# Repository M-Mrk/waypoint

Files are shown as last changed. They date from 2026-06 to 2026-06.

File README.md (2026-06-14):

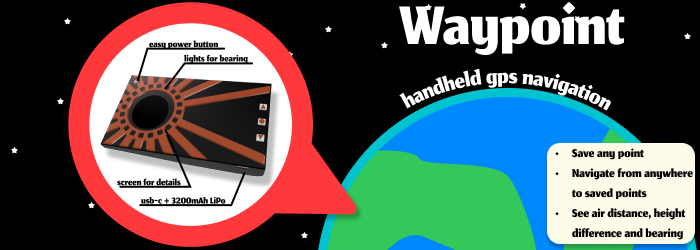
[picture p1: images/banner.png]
banner image


# Waypoint
A handheld GNSS navigation device designed to help you to get to a destination without relying on mobile reception.

Ever wanted to get somewhere from anywhere? Waypoint uses GNSS to guide you towards your destination by showing the direction, distance, and elevation difference. It does not provide turn-by-turn routes, but instead gives you all the other needed informations to navigate independently.

It is powered by a 3200mAh LiPo battery, an efficient MCU, and separated power domains to achieve long battery life.

## How to use it

1. Save your current location
2. Travel somewhere else
3. Select your saved location
4. Navigate back using the provided direction and distance information

## Why

I built Waypoint for [Fallout 2026](https://fallout.hackclub.com) because I wanted to create a project involving RF and battery management.

With this project I learned a lot about embedded Rust with the embassy framework.

## Specs
- 20 sk6812s LEDs to indicate the needed bearing
- 240x240 GC9A01 oled screen
- ATGM336H GNSS module
- Esp32-c6
- usb-c charging
- imu + magnetometer
- haptics (DRV2605L + LRE)

# Pictures
## Full assembly
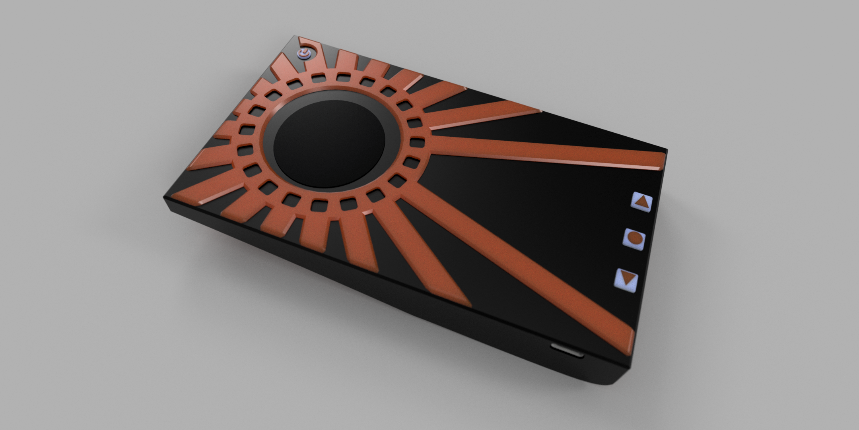
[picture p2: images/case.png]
case


## PCB
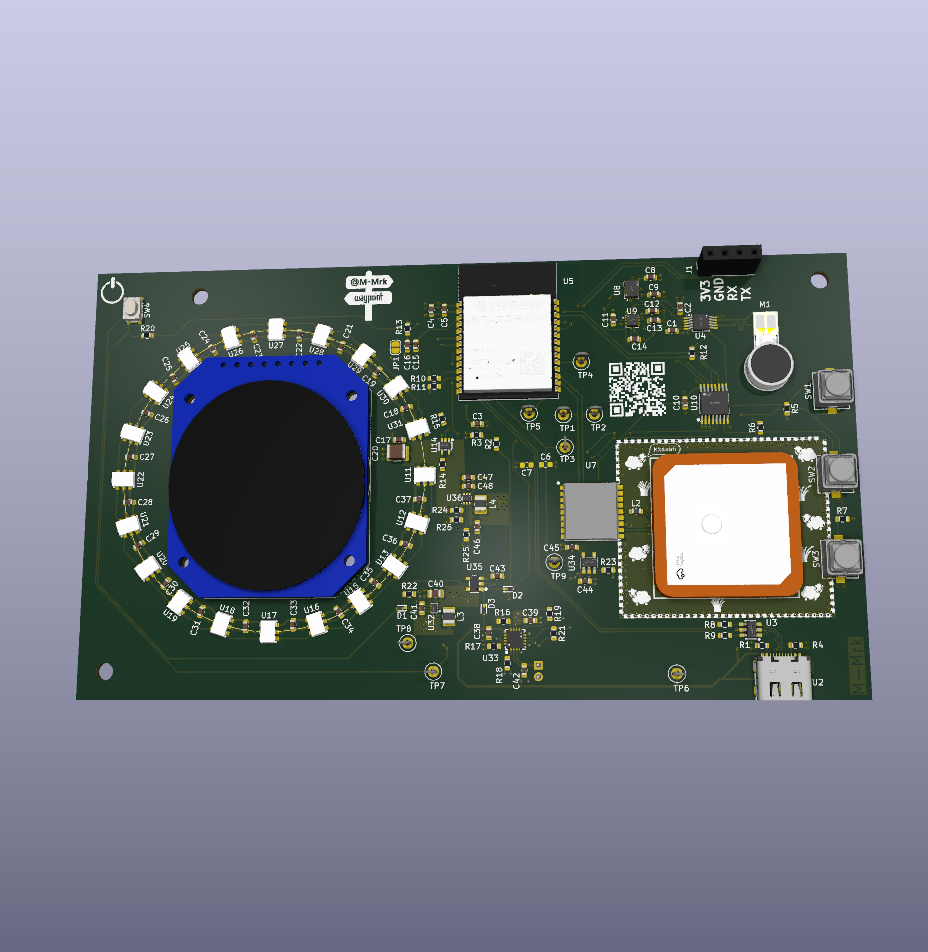
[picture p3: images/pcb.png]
pcb


## Magazine page
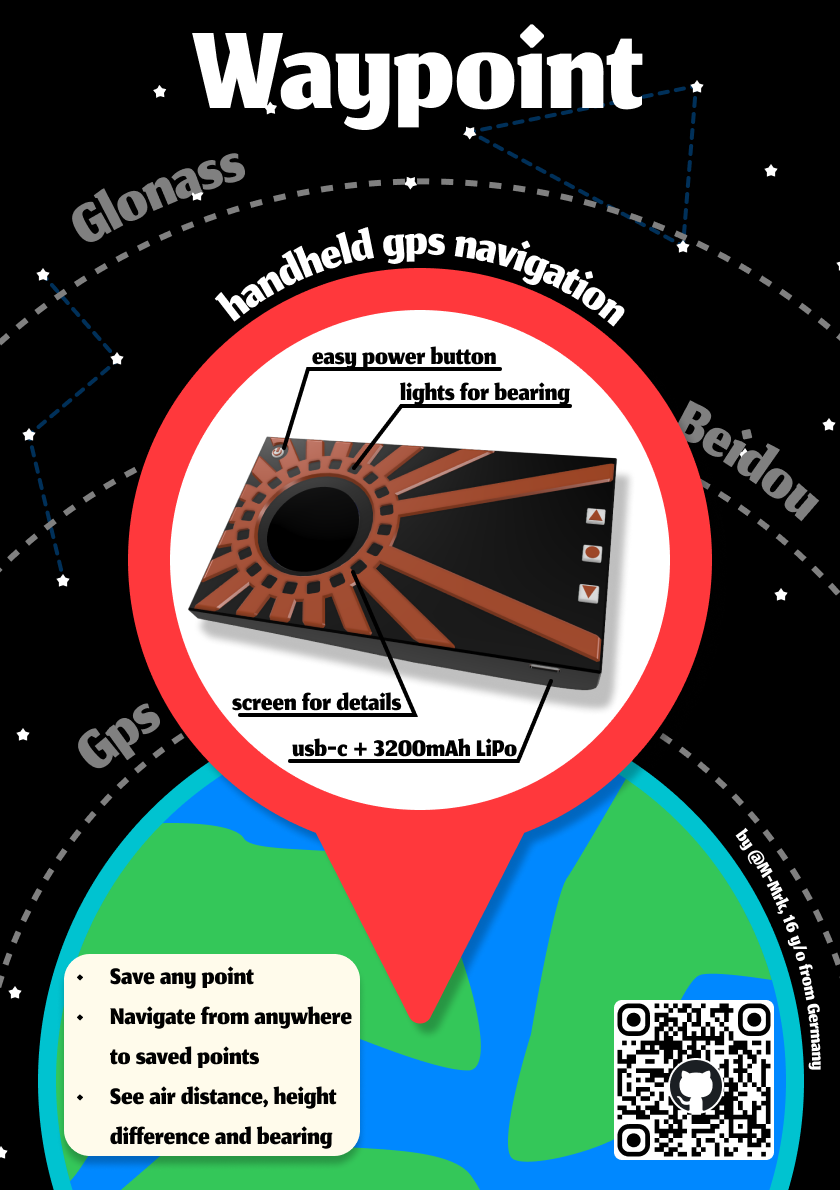
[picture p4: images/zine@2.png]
zine


# Build it yourself
## PCB
Order all components from the [bom](bom.csv) from your prefered site. It already includes links to lcsc and aliexpress. Also order the pcb from the [releases](https://github.com/M-Mrk/waypoint/releases) with the gerbers. I would recommend getting a stencil as the design includes some tricky footprints.

## Soldering
Start by soldering all smd components, then do all the tht ones.

## Case
Print all .3mf files in [here](case/printables/). Printing the top and bottom in different colors gives it a nice touch! See the example images for inspiration.

## Flashing
Get the firmware file from [releases](https://github.com/M-Mrk/waypoint/releases). Flash it with ur prefered esp flashing tool over the usb port or the exposed uart. You can use espflash or [espressifs web tool](https://espressif.github.io/esptool-js/)

## Assembly
- Stick the battery in the bottom of the case and connected it to the pcb (please make sure that the batteries polarity matches the pcbs)
- Press the pcb into the bottom. Align it with the posts
- The top requires some force to press on, as it uses snap fits. If there is too much friction sand the lip a bit down.
- Done

# BOM
|Reference |Qty|Value |Footprint |LCSC Part|MOQ|Unit price (€)|Total price (€)|Link |
|---|---|---|---|---|---|---|---|---|
|C1;C2;C3;C15;C38;C43;C44;C45 |8  |1uF |Capacitor_SMD:C_0603_1608Metric |C19702 |20 |0.0154 |0.31 |https://lcsc.com/product-detail/C19702.html |
|C4;C47;C48 |3  |22uF |Capacitor_SMD:C_0603_1608Metric |C86295 |10 |0.0283 |0.28 |https://lcsc.com/product-detail/C86295.html |
|C5;C8;C9;C10;C11;C12;C16;C17;C18;C19;C21;C22;C23;C24;C25;C26;C27;C28;C29;C30;C31;C32;C33;C34;C35;C36;C37|27 |100nF |Capacitor_SMD:C_0603_1608Metric |C143640  |100|0.0062 |0.62 |https://lcsc.com/product-detail/C143640.html |
|C13;C46 |2  |10uF |Capacitor_SMD:C_0603_1608Metric |C96446 |20 |0.0472 |0.94 |https://lcsc.com/product-detail/C96446.html |
|C14 |1  |220nF |Capacitor_SMD:C_0603_1608Metric |C107083  |50 |0.0119 |0.6 |https://lcsc.com/product-detail/C107083.html |
|C20 |1  |100uF |Capacitor_SMD:C_1210_3225Metric |C7432790 |1  |0.3025 |0.3 |https://lcsc.com/product-detail/C7432790.html |
|C39;C41;C42 |3  |4.7uF |Capacitor_SMD:C_0603_1608Metric |C19666 |10 |0.0192 |0.19 |https://lcsc.com/product-detail/C19666.html |
|C40 |1  |2.2uF |Capacitor_SMD:C_0805_2012Metric |C19110 |10 |0.0203 |0.2 |https://lcsc.com/product-detail/C19110.html |
|D1;D2;D3 |3  |BAT54X |lcsc_lib:SOD-523_L1.2-W0.8-LS1.6-RD |C51315114|50 |0.0040 |0.2 |https://lcsc.com/product-detail/C51315114.html |
|L1 |1  |KH-GPS252504-WY |lcsc_lib:ANT-TH_KH-GPS252504-WY |C962216  |1  |0.9211 |0.92 |https://lcsc.com/product-detail/C962216.html |
|L2 |1  |47nH |Inductor_SMD:L_0603_1608Metric |C6807998 |20 |0.0336 |0.67 |https://lcsc.com/product-detail/C6807998.html |
|L3;L4 |2  |1uH |Inductor_SMD:L_1008_2520Metric |C5179444 |10 |0.0578 |0.58 |https://lcsc.com/product-detail/C5179444.html |
|M1 |1  |LD0832AA-0126F |lcsc_lib:MD-SMD_2P-LD0832AA-0126F |C2942349 |1  |1.4234 |1.42 |https://lcsc.com/product-detail/C2942349.html |
|R1;R4 |2  |5.1kR |Resistor_SMD:R_0603_1608Metric |C2907114 |100|0.0013 |0.13 |https://lcsc.com/product-detail/C2907114.html |
|R2;R5;R6;R7;R12;R13;R18;R19;R21 |9  |10kR |Resistor_SMD:R_0603_1608Metric |C2930027 |100|0.0013 |0.13 |https://lcsc.com/product-detail/C2930027.html |
|R3 |1  |30kR |Resistor_SMD:R_0603_1608Metric |C2907025 |100|0.0015 |0.15 |https://lcsc.com/product-detail/C2907025.html |
|R8;R9 |2  |22R |Resistor_SMD:R_0603_1608Metric |C2907129 |100|0.0013 |0.13 |https://lcsc.com/product-detail/C2907129.html |
|R10;R11 |2  |2.2kR |Resistor_SMD:R_0603_1608Metric |C2907005 |100|0.0014 |0.14 |https://lcsc.com/product-detail/C2907005.html |
|R14;R15 |2  |510R |Resistor_SMD:R_0603_1608Metric |C2907179 |100|0.0013 |0.13 |https://lcsc.com/product-detail/C2907179.html |
|R16 |1  |1.2kR |Resistor_SMD:R_0603_1608Metric |C2907081 |100|0.0012 |0.12 |https://lcsc.com/product-detail/C2907081.html |
|R17 |1  |1.96kR |Resistor_SMD:R_0603_1608Metric |C2998107 |100|0.0013 |0.13 |https://lcsc.com/product-detail/C2998107.html |
|R20;R22;R23;R25;R26 |5  |100kR |Resistor_SMD:R_0603_1608Metric |C2906980 |100|0.0014 |0.14 |https://lcsc.com/product-detail/C2906980.html |
|R24 |1  |732kR |Resistor_SMD:R_0603_1608Metric |C2849083 |5  |0.0710 |0.36 |https://lcsc.com/product-detail/C2849083.html |
|SW1 |1  |Nav buttons |lcsc_lib:SW-SMD_L6.0-W6.0-LS6.6 |C49174518|5  |0.0671 |0.34 |https://lcsc.com/product-detail/C49174518.html |
|SW4 |1  |SKRPACE010 |lcsc_lib:KEY-SMD_4P-L4.2-W3.2-P2.20-LS4.6 |C139797  |10 |0.0549 |0.55 |https://lcsc.com/product-detail/C139797.html |
|U1 |1  |BX-PH2.0-2PWZ |lcsc_lib:CONN-TH_2P-P2.00_BX-PH2.0-2PWZ |C18077753|50 |0.0085 |0.43 |https://lcsc.com/product-detail/C18077753.html |
|U2 |1  |GT-USB-7010ASV |lcsc_lib:USB-C-SMD_G-SWITCH_GT-USB-7010ASV|C2988369 |5  |0.0773 |0.39 |https://lcsc.com/product-detail/C2988369.html |
|U3 |1  |USBLC6-2SC6_C5261088 |lcsc_lib:SOT-23-6_L2.9-W1.6-P0.95-LS2.8-BR|C5261088 |5  |0.0339 |0.17 |https://lcsc.com/product-detail/C5261088.html |
|U4 |1  |DRV2605LDGST |lcsc_lib:VSSOP-10_L3.0-W3.0-P0.50-LS4.9-BL|C425927  |1  |1.1835 |1.18 |https://lcsc.com/product-detail/C425927.html |
|U5 |1  |ESP32-C6-WROOM-1-N8 |lcsc_lib:WIRELM-SMD_ESP32-C6-WROOM-1 |C5366877 |1  |3.8269 |3.83 |https://lcsc.com/product-detail/C5366877.html |
|U6 |1  |240x240 SPI |aliexpress:GC9A01 | |1  |3.29 |3.29 |https://de.aliexpress.com/item/1005010527932589.html|
|U7 |1  |ATGM336H-5NR-32 |lcsc_lib:GPS-SMD_18P-L10.1-W9.7-P1.10-TL  |C5117921 |1  |1.7764 |1.78 |https://lcsc.com/product-detail/C5117921.html |
|U8 |1  |LSM6DS3TR-C |lcsc_lib:LGA-14_L3.0-W2.5-P0.50-TL |C967633  |1  |1.3916 |1.39 |https://lcsc.com/product-detail/C967633.html |
|U9 |1  |IIS2MDCTR |lcsc_lib:LGA-12_L2.0-W2.0-P0.50-TL |C2655002 |1  |2.7994 |2.8 |https://lcsc.com/product-detail/C2655002.html |
|U10 |1  |TCA9534PWR |lcsc_lib:TSSOP-16_L5.0-W4.4-P0.65-LS6.4-BL|C783615  |1  |0.6794 |0.68 |https://lcsc.com/product-detail/C783615.html |
|U11;U12;U13;U15;U16;U17;U18;U19;U20;U21;U22;U23;U24;U25;U26;U27;U28;U29;U30;U31 |20 |SK6812MINI-FA |lcsc_lib:LED-SMD_SK6812MINI-FA |C7423121 |10 |0.0633 |1.27 |https://lcsc.com/product-detail/C7423121.html |
|U14 |1  |SN74LV1T34DCKR_C48543212|lcsc_lib:SC-70-5_L2.1-W1.3-P0.65-LS2.1-BR |C48543212|5  |0.0573 |0.29 |https://lcsc.com/product-detail/C48543212.html |
|U32 |1  |TPS62237DRYR |lcsc_lib:SON-6_L1.5-W1.0-P0.50-BL |C398923  |1  |0.7050 |0.71 |https://lcsc.com/product-detail/C398923.html |
|U33 |1  |BQ24073RGTR |lcsc_lib:QFN-16_L3.0-W3.0-P0.50-TL-EP1.7  |C15220 |1  |0.6966 |0.7 |https://lcsc.com/product-detail/C15220.html |
|U34 |1  |LP5907MFX-3.3/NOPB |lcsc_lib:SOT-23-5_L3.0-W1.7-P0.95-LS2.8-BR|C80670 |5  |0.1446 |0.72 |https://lcsc.com/product-detail/C80670.html |
|U35 |1  |TPS3840DL35DBVR |lcsc_lib:SOT-23-5_L2.9-W1.6-P0.95-LS2.8-BR|C2866251 |1  |0.5365 |0.54 |https://lcsc.com/product-detail/C2866251.html |
|U36 |1  |TPS61023DRLR |lcsc_lib:SOT-563_L1.6-W1.2-P0.50-LS1.6-BR |C919459  |5  |0.2357 |1.18 |https://lcsc.com/product-detail/C919459.html |
|PCB |1  |JLC 1.6mm 4-Layers | | |5  |5.37 |26.85 |https://cart.jlcpcb.com/quote |
|Stencil |1  |Default | | |1  |6.18 |6.18 |https://cart.jlcpcb.com/quote |
Total (w/o shipping): 64.06€

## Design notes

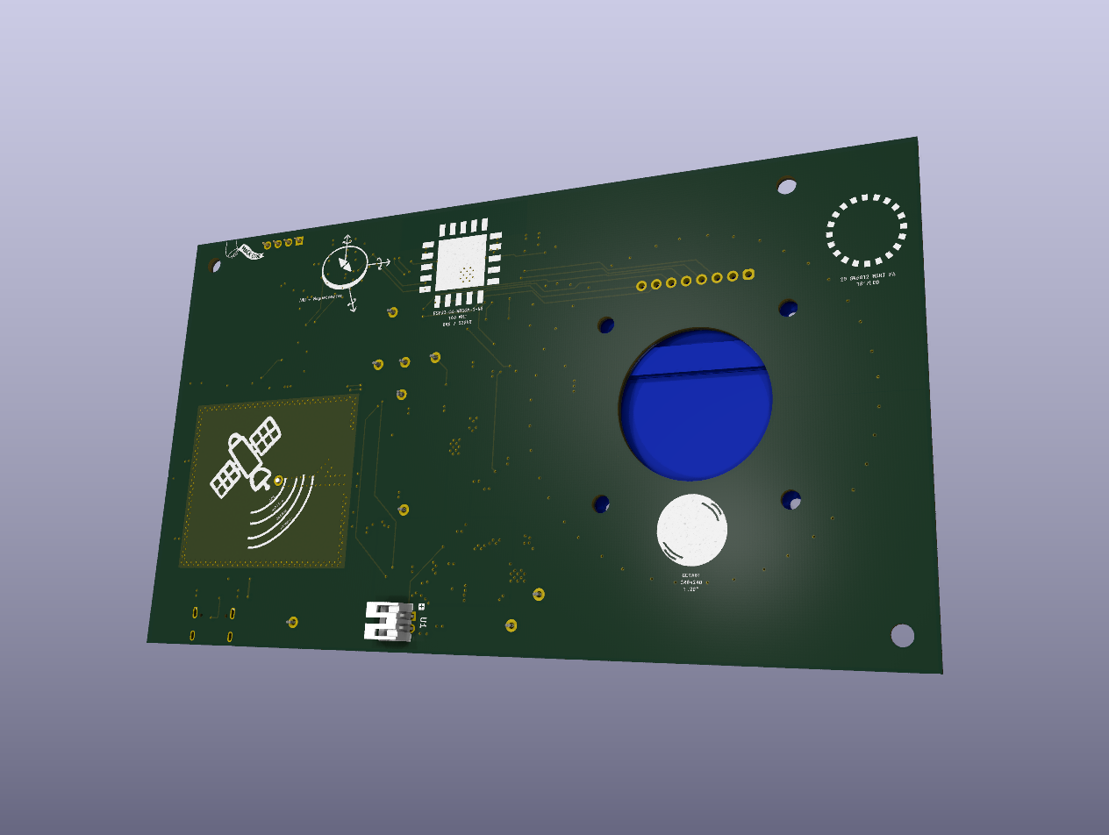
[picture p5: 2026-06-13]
images/pcb-back.png

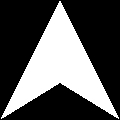
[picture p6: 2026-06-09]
firmware/img/navigate.bmp

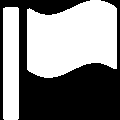
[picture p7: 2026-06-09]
firmware/img/flag.bmp

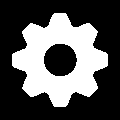
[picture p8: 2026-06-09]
firmware/img/cog.bmp

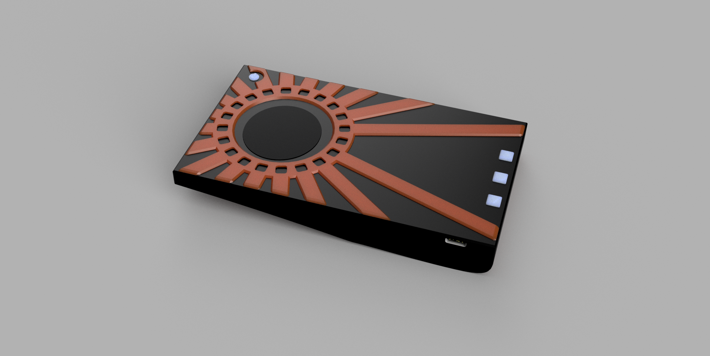
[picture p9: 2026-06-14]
images/case corner.png

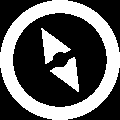
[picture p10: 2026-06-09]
firmware/img/compass.bmp

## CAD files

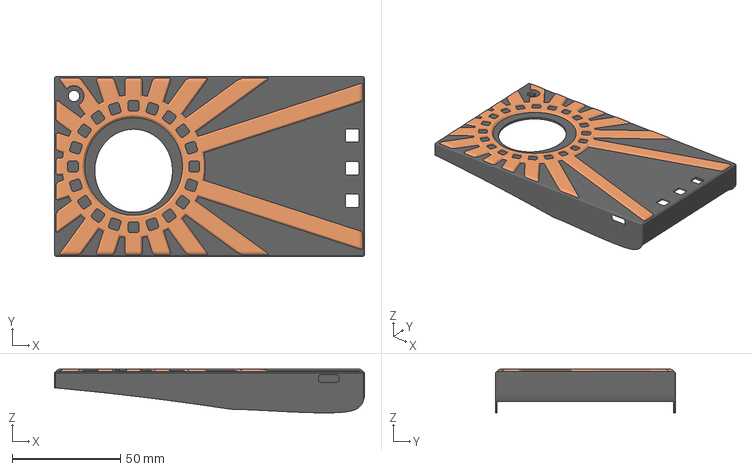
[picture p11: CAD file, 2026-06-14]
case/printables/top.3mf
143.0 x 83.0 x 20.2 mm

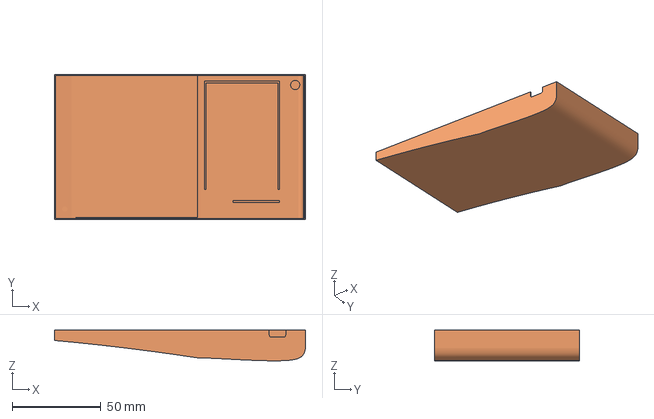
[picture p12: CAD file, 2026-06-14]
case/printables/bottom.3mf
141.6 x 81.6 x 17.3 mm

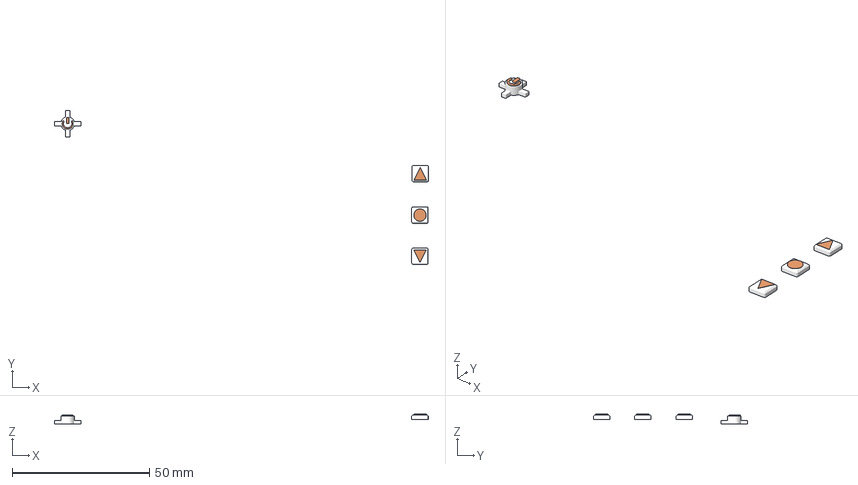
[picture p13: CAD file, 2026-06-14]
case/printables/buttons.3mf
136.2 x 56.1 x 3.53 mm

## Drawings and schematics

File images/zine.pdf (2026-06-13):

# Waypoint

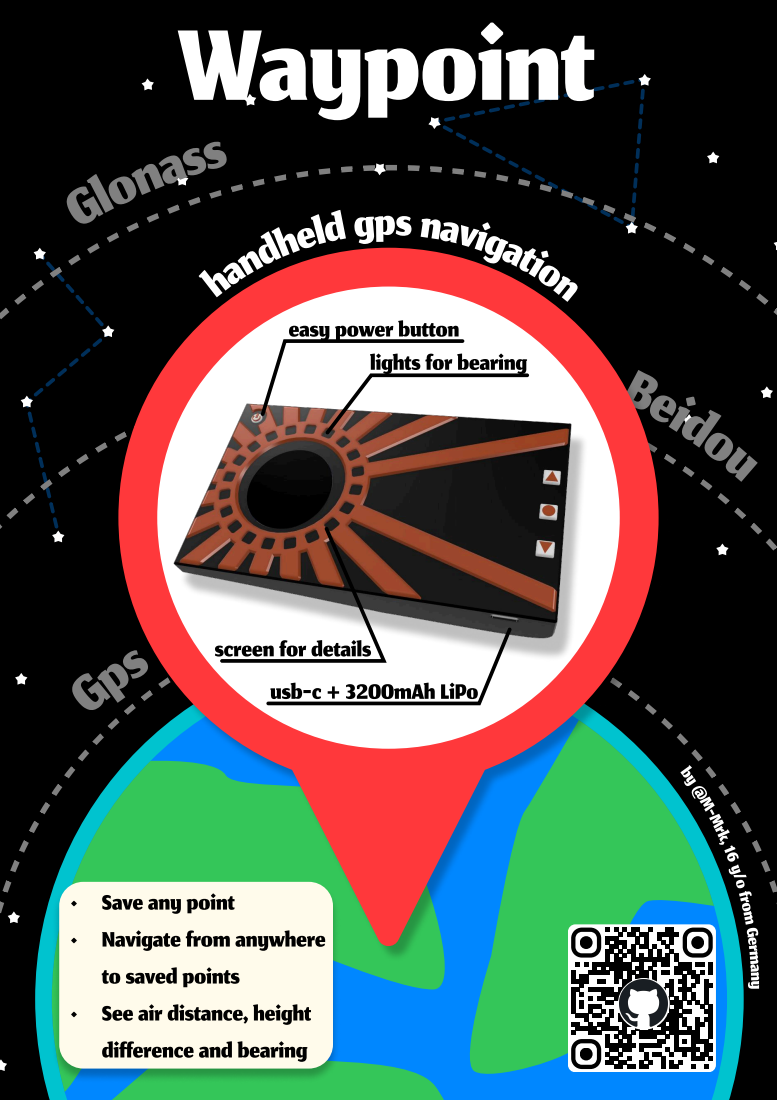
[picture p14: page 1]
usb-c + 3200mAh LiPo

easy power button lights for bearing

screen for details

Save any point

Navigate from anywhere to saved points

See air distance, height difference and bearing

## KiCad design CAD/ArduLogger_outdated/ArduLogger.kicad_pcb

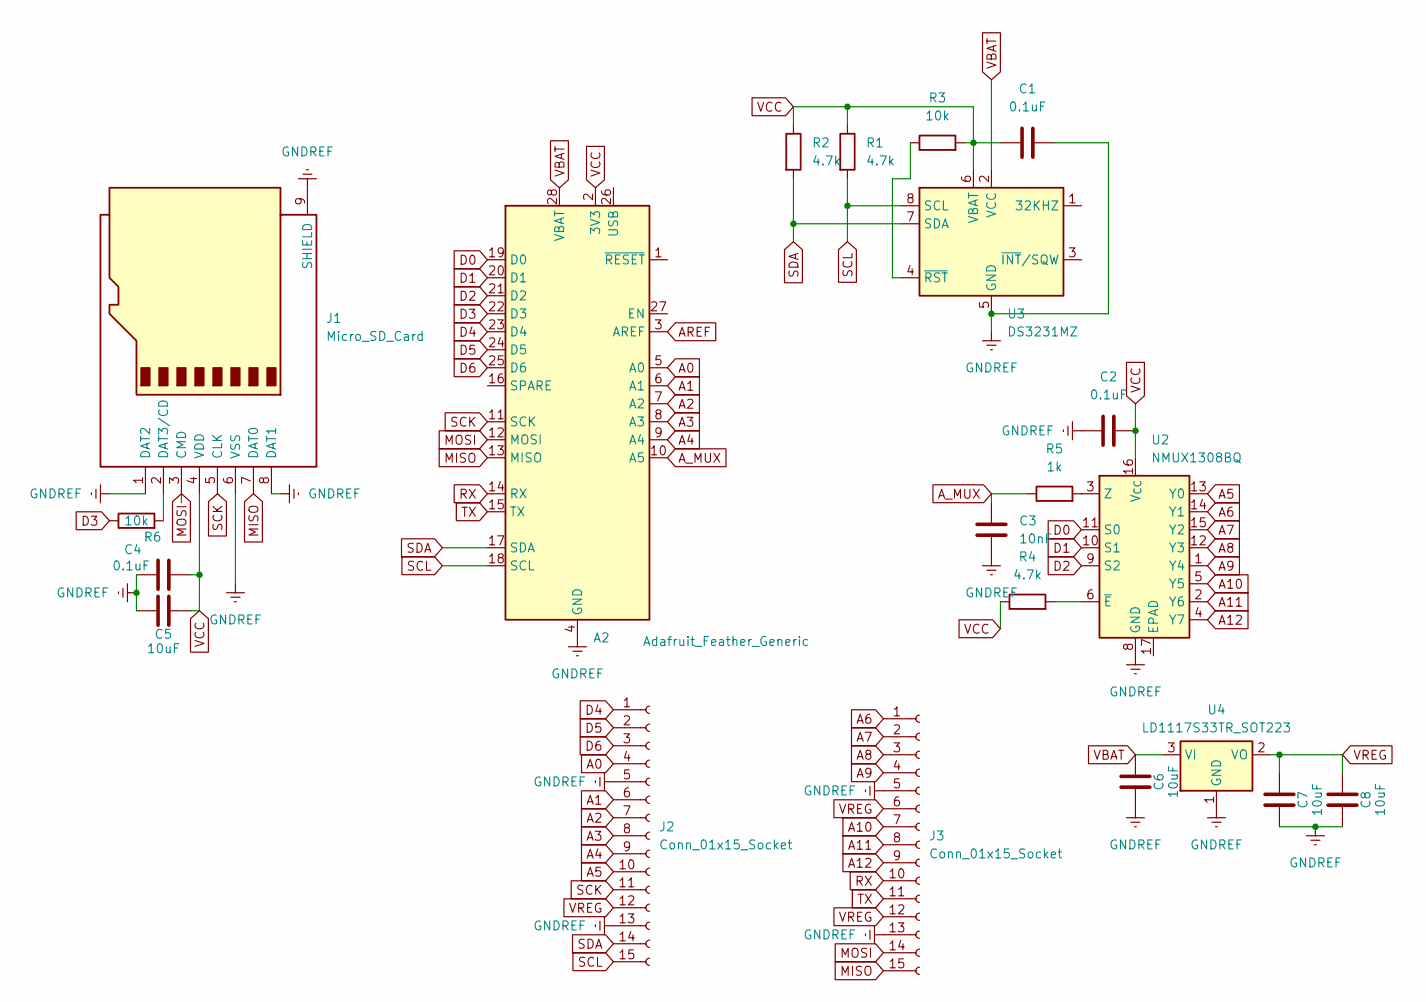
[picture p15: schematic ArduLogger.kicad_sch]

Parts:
A2: Adafruit_Feather_Generic; Adafruit_Feather
C1, C2, C4: 0.1uF; C_0603_1608Metric
C3: 10nF; C_0603_1608Metric
C5, C6, C7, C8: 10uF; C_0603_1608Metric
J1: Micro_SD_Card; microSD_HC_Wuerth_693072010801
J2, J3: Conn_01x15_Socket; PhoenixContact_MSTBVA_2,5_15-G-5,08_1x15_P5.08mm_Vertical
R1, R2, R4: 4.7k; R_0603_1608Metric
R3, R6: 10k; R_0603_1608Metric
R5: 1k; R_0603_1608Metric
U2: NMUX1308BQ; DHVQFN-16-1EP_2.5x3.5mm_P0.5mm_EP1x2mm
U3: DS3231MZ; SOIC-8_3.9x4.9mm_P1.27mm
U4: LD1117S33TR_SOT223; SOT-223-3_TabPin2

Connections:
A0: A2.5 (A0), J2.4
A1: A2.6 (A1), J2.6
A2: A2.7 (A2), J2.7
A3: A2.8 (A3), J2.8
A4: A2.9 (A4), J2.9
A5: J2.10, U2.13 (Y0)
A6: J3.1, U2.14 (Y1)
A7: J3.2, U2.15 (Y2)
A8: J3.3, U2.12 (Y3)
A9: J3.4, U2.1 (Y4)
A10: J3.7, U2.5 (Y5)
A11: J3.8, U2.2 (Y6)
A12: J3.9, U2.4 (Y7)
AREF: A2.3 (AREF)
A_MUX: A2.10 (A5), C3.1, R5.1
D0: A2.19 (D0), U2.11 (S0)
D1: A2.20 (D1), U2.10 (S1)
D2: A2.21 (D2), U2.9 (S2)
D3: A2.22 (D3), R6.1
D4: A2.23 (D4), J2.1
D5: A2.24 (D5), J2.2
D6: A2.25 (D6), J2.3
GNDREF: A2.4 (GND), C1.2, C2.1, C3.2, C4.1, C5.1, C6.1, C7.1, C8.1, J1.1 (DAT2), J1.6 (VSS), J1.8 (DAT1), J1.9 (SHIELD), J2.5, J2.13, J3.5, J3.13, U2.8 (GND), U3.5 (GND), U4.1 (GND)
MISO: A2.13 (MISO), J1.7 (DAT0), J3.15
MOSI: A2.12 (MOSI), J1.3 (CMD), J3.14
unnamed: J1.2 (DAT3/CD), R6.2
unnamed: R5.2, U2.3 (Z)
unnamed: R4.2, U2.6 (~E)
unnamed: R3.1, U3.4 (~RST)
RX: A2.14 (RX), J3.10
SCK: A2.11 (SCK), J1.5 (CLK), J2.11
SCL: A2.18 (SCL), J2.15, R1.2, U3.8 (SCL)
SDA: A2.17 (SDA), J2.14, R2.2, U3.7 (SDA)
TX: A2.15 (TX), J3.11
VBAT: A2.28 (VBAT), C6.2, U3.2 (VCC), U4.3 (VI)
VCC: A2.2 (3V3), C1.1, C2.2, C4.2, C5.2, J1.4 (VDD), R1.1, R2.1, R3.2, R4.1, U2.16 (V_{CC}), U3.6 (VBAT)
VREG: C7.2, C8.2, J2.12, J3.6, J3.12, U4.2 (VO)

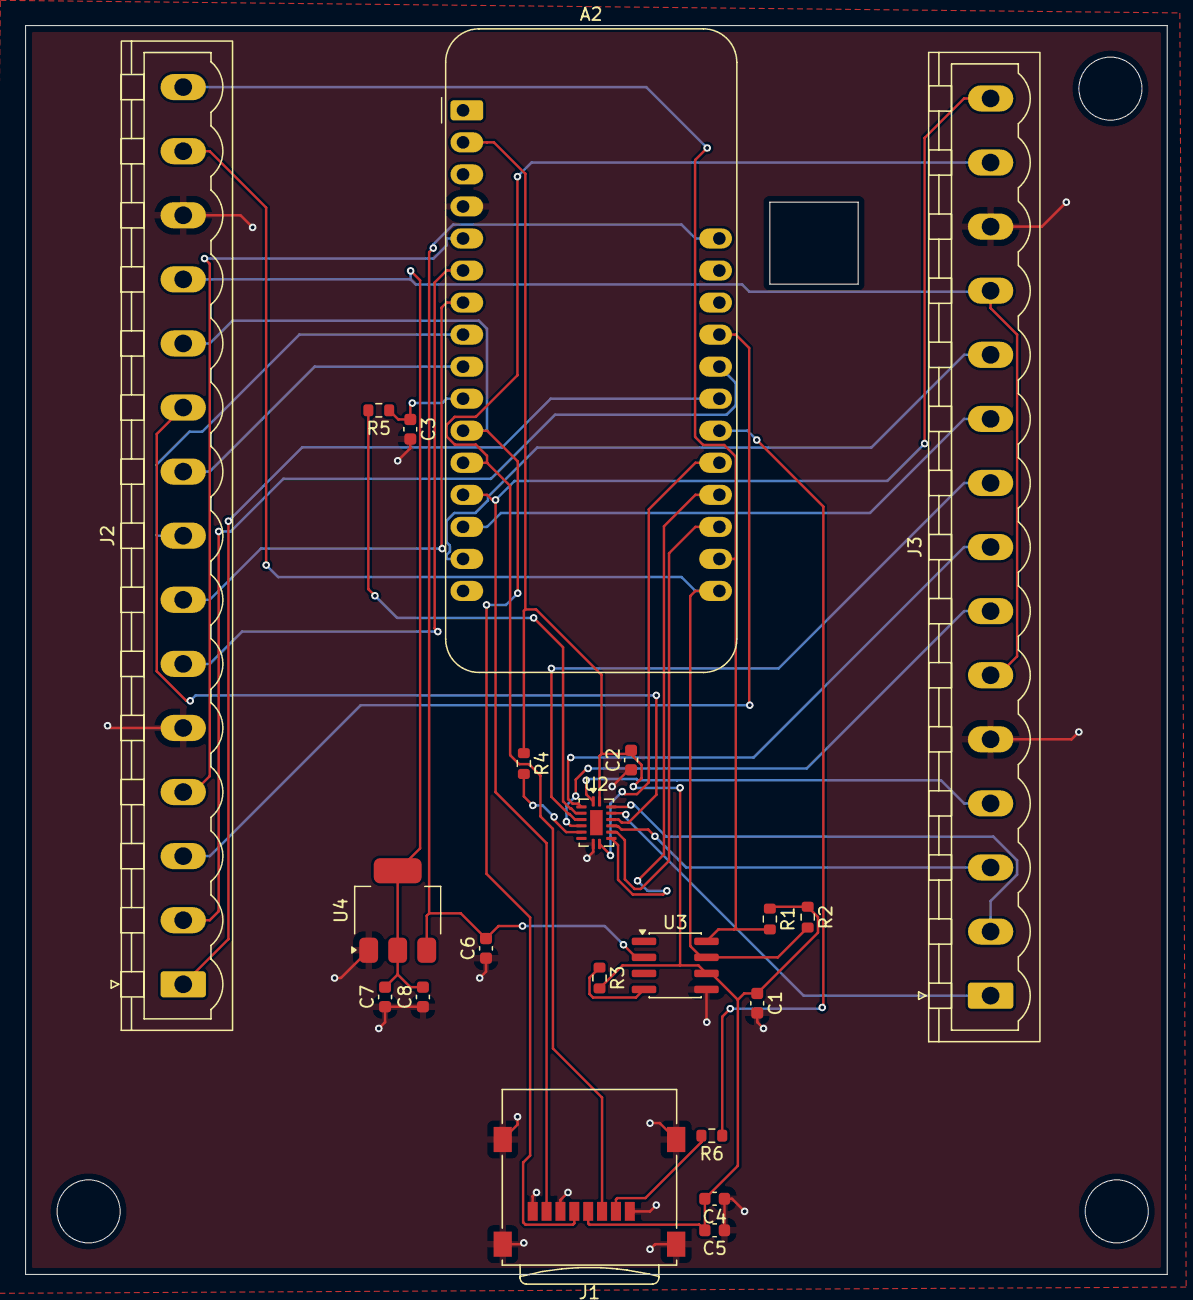
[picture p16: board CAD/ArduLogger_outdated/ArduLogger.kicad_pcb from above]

Board: 2 copper layers, 90.5 x 99.0 mm, 21 parts (0 on the bottom side), 36 nets.

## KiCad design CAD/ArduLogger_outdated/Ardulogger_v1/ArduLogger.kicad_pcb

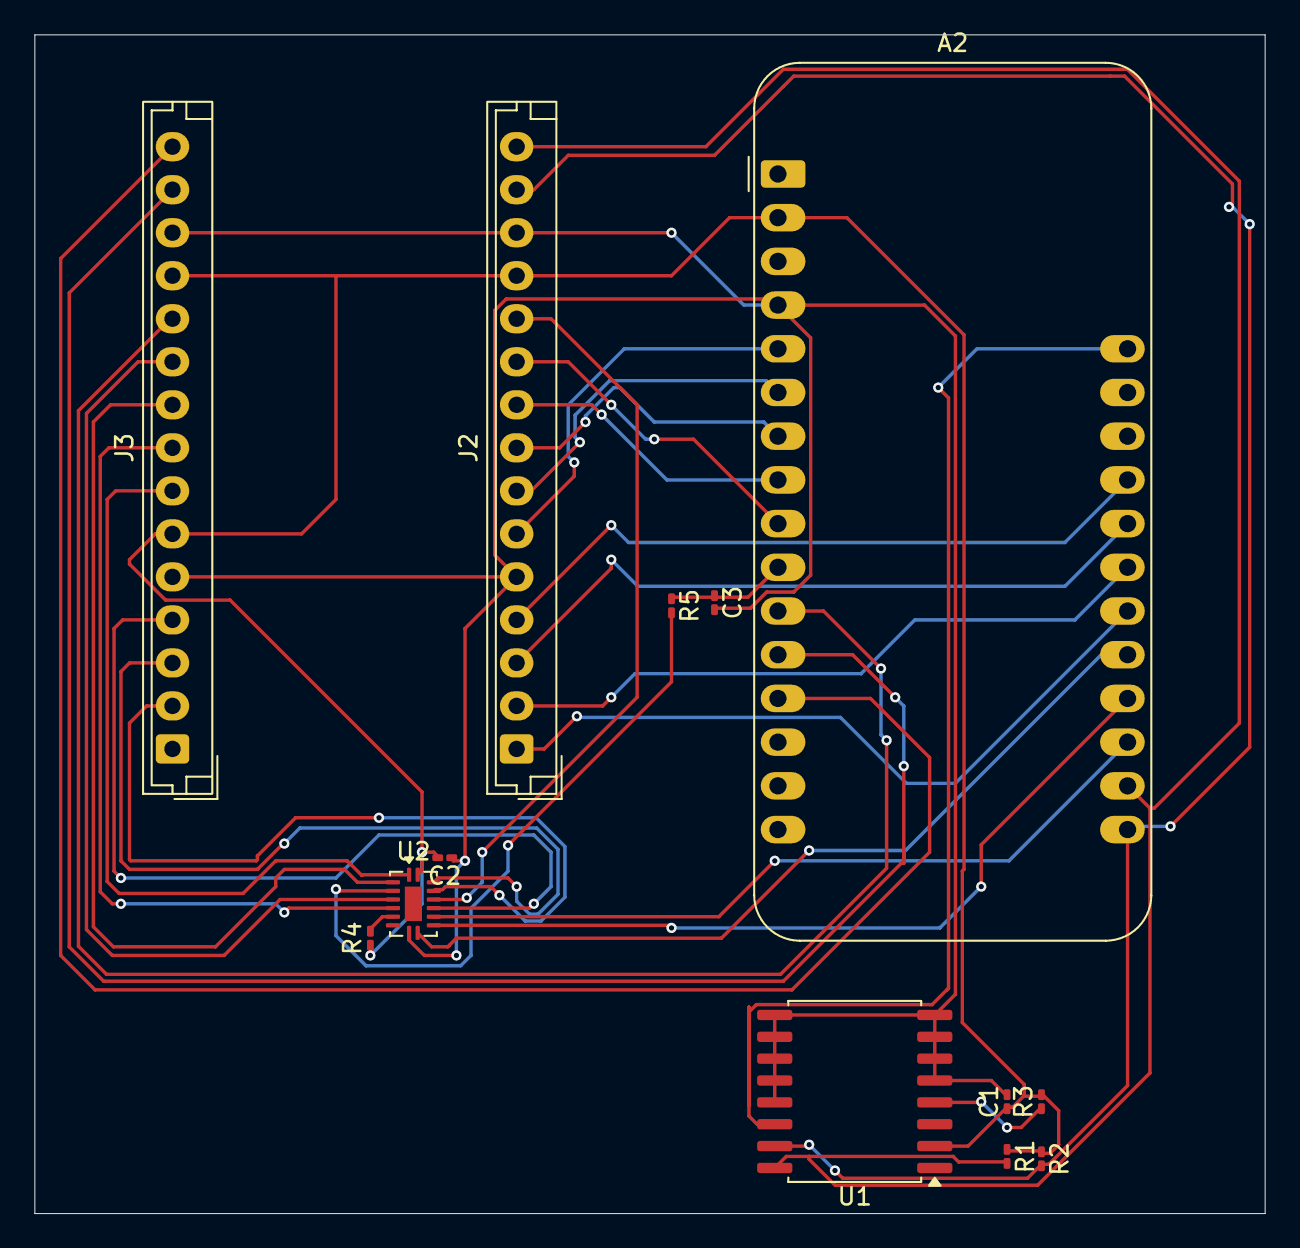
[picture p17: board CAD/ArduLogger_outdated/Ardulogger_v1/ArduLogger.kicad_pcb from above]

Board: 2 copper layers, 71.5 x 68.5 mm, 13 parts (0 on the bottom side), 32 nets.

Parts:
A2: Adafruit_Feather_Generic; Adafruit_Feather
C1, C2: 0.1uF; C_0201_0603Metric_Pad0.64x0.40mm_HandSolder
C3: 10nF; C_0201_0603Metric_Pad0.64x0.40mm_HandSolder
J2, J3: Conn_01x15_Socket; JST_EH_B15B-EH-A_1x15_P2.50mm_Vertical
R1, R2, R4: 4.7k; R_0201_0603Metric_Pad0.64x0.40mm_HandSolder
R3: 10k; R_0201_0603Metric_Pad0.64x0.40mm_HandSolder
R5: 100; R_0201_0603Metric_Pad0.64x0.40mm_HandSolder
U1: DS3231M; SOIC-16W_7.5x10.3mm_P1.27mm
U2: NMUX1308BQ; DHVQFN-16-1EP_2.5x3.5mm_P0.5mm_EP1x2mm

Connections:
A0: A2.5 (A0), J2.6
A1: A2.6 (A1), J2.7
A2: A2.7 (A2), J2.8
A3: A2.8 (A3), J2.9
A4: A2.9 (A4), J2.10
A5: J2.11, U2.13 (Y0)
A6: J3.2, U2.14 (Y1)
A7: J3.3, U2.15 (Y2)
A8: J3.4, U2.12 (Y3)
A9: J3.7, U2.1 (Y4)
A10: J3.8, U2.5 (Y5)
A11: J3.9, U2.2 (Y6)
A12: J3.10, U2.4 (Y7)
A_MUX: A2.10 (A5), C3.1, R5.1
D0: A2.19 (D0), U2.11 (S0)
D1: A2.20 (D1), U2.10 (S1)
D2: A2.21 (D2), U2.9 (S2)
D3: A2.22 (D3), J2.1
D4: A2.23 (D4), J2.2
D5: A2.24 (D5), J2.3
D6: A2.25 (D6), J2.4
GNDREF: A2.4 (GND), C1.2, C2.1, C3.2, J2.5, J2.13, J3.5, J3.13, U1.5 (GND), U1.6 (GND), U1.7 (GND), U1.8 (GND), U1.9 (GND), U1.10 (GND), U1.11 (GND), U1.12 (GND), U1.13 (GND), U2.8 (GND)
MISO: A2.13 (MISO), J3.15
MOSI: A2.12 (MOSI), J3.14
unnamed: A2.28 (VBAT), U1.14 (VBAT)
unnamed: R3.1, U1.4 (~RST)
unnamed: R5.2, U2.3 (Z)
unnamed: R4.2, U2.6 (~E)
SCK: A2.11 (SCK), J3.11
SCL: A2.18 (SCL), J2.15, R1.2, U1.16 (SCL)
SDA: A2.17 (SDA), J2.14, R2.2, U1.15 (SDA)
VCC: A2.2 (3V3), C1.1, C2.2, J2.12, J3.6, J3.12, R1.1, R2.1, R3.2, R4.1, U1.2 (VCC), U2.16 (V_{CC})

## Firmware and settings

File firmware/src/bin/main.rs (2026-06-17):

#![no_std]
#![no_main]
#![deny(
    clippy::mem_forget,
    reason = "mem::forget is generally not safe to do with esp_hal types, especially those \
    holding buffers for the duration of a data transfer."
)]
#![deny(clippy::large_stack_frames)]

use core::cell::RefCell;
use defmt::{error, info};
use embassy_sync::blocking_mutex::Mutex;
use embassy_sync::blocking_mutex::raw::CriticalSectionRawMutex;
use static_cell::StaticCell;

use embassy_embedded_hal::shared_bus::blocking::i2c::I2cDevice;
use embassy_executor::Spawner;
use embassy_time::{Duration, Timer};

use esp_backtrace as _;
use esp_hal::analog::adc;
use esp_hal::clock::CpuClock;
use esp_hal::gpio;
use esp_hal::i2c::master as hardware_i2c;
use esp_hal::rmt;
use esp_hal::spi;
use esp_hal::timer::timg::TimerGroup;
use esp_hal::uart;
use esp_println as _;

extern crate alloc;

use firmware::{inputs, logic, outputs, power};

// This creates a default app-descriptor required by the esp-idf bootloader.
// For more information see: <https://docs.espressif.com/projects/esp-idf/en/stable/esp32/api-reference/system/app_image_format.html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>
esp_bootloader_esp_idf::esp_app_desc!();

static I2C_BUS: StaticCell<
    Mutex<CriticalSectionRawMutex, RefCell<hardware_i2c::I2c<'static, esp_hal::Blocking>>>,
> = StaticCell::new();

#[allow(
    clippy::large_stack_frames,
    reason = "it's not unusual to allocate larger buffers etc. in main"
)]
#[esp_rtos::main]
async fn main(spawner: Spawner) -> ! {
    // generator version: 1.3.0
    // generator parameters: --chip esp32c6 -o esp32c6-wroom-1 -o unstable-hal -o embassy -o defmt -o esp-backtrace -o vscode -o neovim

    let config = esp_hal::Config::default().with_cpu_clock(CpuClock::max());
    let peripherals = esp_hal::init(config);

    // The following pins are used to bootstrap the chip. They are available
    // for use, but check the datasheet of the module for more information on them.
    // - GPIO4
    // - GPIO5
    // - GPIO8
    // - GPIO9
    // - GPIO15
    // These GPIO pins are in use by some feature of the module and should not be used.
    let _ = peripherals.GPIO24;
    let _ = peripherals.GPIO25;
    let _ = peripherals.GPIO26;
    let _ = peripherals.GPIO27;
    let _ = peripherals.GPIO28;
    let _ = peripherals.GPIO29;
    let _ = peripherals.GPIO30;

    let main_power_en = gpio::Output::new(
        peripherals.GPIO9,
        gpio::Level::High,
        gpio::OutputConfig::default(),
    );

    esp_alloc::heap_allocator!(#[esp_hal::ram(reclaimed)] size: 65536);

    let timg0 = TimerGroup::new(peripherals.TIMG0);
    let sw_interrupt =
        esp_hal::interrupt::software::SoftwareInterruptControl::new(peripherals.SW_INTERRUPT);
    esp_rtos::start(timg0.timer0, sw_interrupt.software_interrupt0);

    info!("Embassy initialized!");

    // TODO: Spawn some tasks
    let _ = spawner;

    // power
    let gnss_power_en = gpio::Output::new(
        peripherals.GPIO8,
        gpio::Level::Low,
        gpio::OutputConfig::default(),
    );

    let leds_power_en = gpio::Output::new(
        peripherals.GPIO0,
        gpio::Level::Low,
        gpio::OutputConfig::default(),
    );

    let power_en_pins = power::PowerPins {
        main_en: main_power_en,
        gnss_en: gnss_power_en,
        leds_en: leds_power_en,
    };

    let mut battery_adc_config = adc::AdcConfig::new();
    let batt_pin = battery_adc_config.enable_pin(peripherals.GPIO1, adc::Attenuation::_11dB);
    let batt_sense = adc::Adc::new(peripherals.ADC1, battery_adc_config).into_async();
    if let Ok(token) = power::power_management_task(power_en_pins, batt_sense, batt_pin) {
        spawner.spawn(token);
    } else {
        error!("Failed to create power task");
    }

    // i2c setup
    let i2c = hardware_i2c::I2c::new(peripherals.I2C0, hardware_i2c::Config::default())
        .unwrap()
        .with_scl(peripherals.GPIO10)
        .with_sda(peripherals.GPIO11);

    let i2c_bus = I2C_BUS.init(Mutex::new(RefCell::new(i2c)));

    // IMU
    let imu_i2c = I2cDevice::new(i2c_bus);
    if let Ok(token) = inputs::sensors::imu::imu_task(imu_i2c) {
        spawner.spawn(token);
    } else {
        error!("Failed to create IMU task");
    }

    // Magnetometer
    let mag_i2c = I2cDevice::new(i2c_bus);
    if let Ok(token) = inputs::sensors::magnetometer::magnetometer_task(mag_i2c) {
        spawner.spawn(token);
    } else {
        error!("Failed to create Magnetometer task")
    }

    // Haptics
    let haptic_i2c = I2cDevice::new(i2c_bus);
    if let Ok(token) = outputs::haptics::haptics_task(haptic_i2c) {
        spawner.spawn(token);
    } else {
        error!("Failed to create Haptics task")
    }

    // I/O Expander
    let expander_int_pin = gpio::Input::new(peripherals.GPIO3, gpio::InputConfig::default());
    let expander_i2c = I2cDevice::new(i2c_bus);
    if let Ok(token) = inputs::expander::expander_task(expander_i2c, expander_int_pin) {
        spawner.spawn(token);
    } else {
        error!("Failed to create expander interrupt task")
    }

    // gnss
    let gnss_uart = uart::Uart::new(
        peripherals.UART1,
        uart::Config::default().with_baudrate(9600),
    )
    .unwrap()
    .with_rx(peripherals.GPIO18)
    .with_tx(peripherals.GPIO19)
    .into_async();

    if let Ok(token) = inputs::gnss::gnss_task(gnss_uart) {
        spawner.spawn(token);
    } else {
        error!("Failed to create gnss task")
    }

    // leds
    let rmt = rmt::Rmt::new(peripherals.RMT, esp_hal::time::Rate::from_mhz(80))
        .unwrap()
        .into_async();
    if let Ok(token) = outputs::leds::leds_task(rmt, peripherals.GPIO23) {
        spawner.spawn(token);
    } else {
        error!("Failed to create led task")
    }

    // display
    let spi = spi::master::Spi::new(peripherals.SPI2, spi::master::Config::default())
        .unwrap()
        .with_mosi(peripherals.GPIO7)
        .with_sck(peripherals.GPIO6);

    let cs = gpio::Output::new(
        peripherals.GPIO20,
        gpio::Level::Low,
        gpio::OutputConfig::default(),
    );
    let dc = gpio::Output::new(
        peripherals.GPIO21,
        gpio::Level::Low,
        gpio::OutputConfig::default(),
    );
    let reset = gpio::Output::new(
        peripherals.GPIO2,
        gpio::Level::Low,
        gpio::OutputConfig::default(),
    );
    if let Ok(token) =
        outputs::display::display_task(spi, cs, dc, reset, peripherals.GPIO22, peripherals.LEDC)
    {
        spawner.spawn(token);
    } else {
        error!("Failed to create display task")
    }

    // Core logic task
    if let Ok(token) = logic::logic_task() {
        spawner.spawn(token);
    } else {
        error!("Failed to create logic task")
    }

    loop {
        Timer::after(Duration::from_secs(5)).await;
        info!("Alive!");
    }
}

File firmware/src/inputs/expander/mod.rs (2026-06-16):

use crate::SharedI2c;
use defmt::{Format, error, info};
use embassy_embedded_hal::shared_bus::blocking::i2c::I2cDevice;
use embassy_futures::select::{Either, select};
use embassy_sync::channel::Channel;
use embassy_sync::mutex::Mutex;
use embassy_sync::once_lock::OnceLock;
use embassy_sync::watch::Watch;
use embassy_sync::{blocking_mutex::raw::CriticalSectionRawMutex, signal::Signal};
use embassy_time::{Duration, Instant};
use esp_hal::gpio::Input;
use esp_hal::i2c::master::I2c as HardwareI2c;
use tca9534_driver_rs::{self as expander, PinConfig, PinLevel};

type ExpanderDevice = tca9534_driver_rs::TCA9534Sync<
    I2cDevice<'static, CriticalSectionRawMutex, HardwareI2c<'static, esp_hal::Blocking>>,
>;

static EXPANDER_CONFIG: OnceLock<Mutex<CriticalSectionRawMutex, CurrentConfig>> = OnceLock::new();

const NUM_PINS: usize = 8;
#[repr(u8)]
#[derive(Clone, Debug)]
pub enum ExpanderPinMapping {
    ChargingIndicator = 0,
    PowerGoodIndicator = 1,
    LeftSwitch = 2,
    OkSwitch = 3,
    ImuInit = 4,
    GnssEnable = 5,
    PowerSwitch = 6,
    RightSwitch = 7,
}
impl ExpanderPinMapping {
    pub fn as_u8(self) -> u8 {
        return self as u8;
    }

    pub fn from_u8(val: u8) -> Option<Self> {
        match val {
            0 => Some(Self::ChargingIndicator),
            1 => Some(Self::PowerGoodIndicator),
            2 => Some(Self::LeftSwitch),
            3 => Some(Self::OkSwitch),
            4 => Some(Self::ImuInit),
            5 => Some(Self::GnssEnable),
            6 => Some(Self::PowerSwitch),
            7 => Some(Self::RightSwitch),
            _ => None,
        }
    }

    pub fn as_usize(self) -> usize {
        return self as usize;
    }

    pub fn as_button_type(self) -> ButtonType {
        match self {
            Self::LeftSwitch => ButtonType::Left,
            Self::OkSwitch => ButtonType::Ok,
            Self::RightSwitch => ButtonType::Right,
            Self::PowerSwitch => ButtonType::Power,
            _ => {
                panic!("Unable to convert self to ButtonType: {:?}", self)
            }
        }
    }
}

pub struct CurrentConfig {
    pins: [PinConfig; NUM_PINS],
    expander: ExpanderDevice,
}

#[derive(Format, Clone, Copy)]
pub enum ButtonType {
    // TODO: implement these
    Left,
    Ok,
    Right,
    Power,
}

#[derive(Format, Clone, Copy)]
pub enum ButtonAction {
    Single,
    Double,
    Long,
}

#[derive(Format, Clone, Copy)]
pub struct ButtonCall {
    pub function: ButtonType,
    pub action: ButtonAction,
}

pub static BTNS: Signal<CriticalSectionRawMutex, ButtonCall> = Signal::new();

pub static IMU_INTERRUPT: Signal<CriticalSectionRawMutex, PinLevel> = Signal::new();
pub static CHARGING: Watch<CriticalSectionRawMutex, bool, 3> = Watch::new();
pub static POWER_GOOD: Watch<CriticalSectionRawMutex, bool, 3> = Watch::new();

pub enum ExpanderCommand {
    SetGnssEnable(PinLevel),
}

pub static EXPANDER_CMD: Channel<CriticalSectionRawMutex, ExpanderCommand, 4> = Channel::new();

async fn initialize(i2c_bus: SharedI2c) {
    let mut expander = expander::TCA9534Sync::new_with_default_address(i2c_bus);
    if expander.init().is_err() {
        error!("Failed to initialize io expander");
        return;
    }

    let pins = [PinConfig::Input; NUM_PINS];
    let config = CurrentConfig {
        pins: pins,
        expander: expander,
    };

    if EXPANDER_CONFIG.init(Mutex::new(config)).is_err() {
        error!("Failed to initialize mutex with expander object");
    }
}

async fn set_default_states() {
    let mutex = EXPANDER_CONFIG.get().await;
    let mut guard = mutex.lock().await;
    let exp_conf = &mut *guard;
    if exp_conf
        .expander
        .set_pin_config(ExpanderPinMapping::GnssEnable.as_u8(), PinConfig::Output)
        .is_err()
    {
        error!("Failed to set GnssEnable pin to output");
        return;
    };
    if exp_conf
        .expander
        .set_pin_output(ExpanderPinMapping::GnssEnable.as_u8(), PinLevel::Low)
        .is_err()
    {
        error!("Failed to set GnssEnable pin to LOW");
        return;
    };
    exp_conf.pins[ExpanderPinMapping::GnssEnable.as_usize()] = PinConfig::Output;
}

fn pin_level_to_bool(level: PinLevel) -> bool {
    match level {
        PinLevel::High => true,
        PinLevel::Low => false,
    }
}

fn is_debounced(last_trigger: &mut Instant) -> bool {
    const DEBOUNCE_DELAY: Duration = Duration::from_millis(20);
    Instant::now() - *last_trigger > DEBOUNCE_DELAY
}

#[embassy_executor::task]
pub async fn expander_task(i2c: SharedI2c, mut int_pin: Input<'static>) {
    initialize(i2c).await;
    set_default_states().await;
    let mutex = EXPANDER_CONFIG.get().await;
    let mut guard = mutex.lock().await;
    let exp_conf = &mut *guard;

    let mut last_left = Instant::now();
    let mut last_ok = Instant::now();
    let mut last_right = Instant::now();
    let mut last_power = Instant::now();

    'main: loop {
        match select(int_pin.wait_for_rising_edge(), EXPANDER_CMD.receive()).await {
            Either::First(_) => {
                let mut causing_pin: Option<u8> = None;
                let mut causing_state: Option<PinLevel> = None;

                'check: for pin in 0..NUM_PINS {
                    if exp_conf.pins[pin] != PinConfig::Input {
                        continue 'check;
                    }
                    let state = match exp_conf.expander.read_pin_input(pin as u8) {
                        Ok(state) => state,
                        Err(_) => {
                            error!("Failed to read from pin {} after Interrupt", &pin);
                            continue 'main;
                        }
                    };
                    if int_pin.is_low() {
                        // Interrupt got disabled, meaning read pin was the cause
                        causing_pin = Some(pin as u8);
                        causing_state = Some(state);
                    }
                }

                match (causing_pin, causing_state) {
                    (Some(pin), Some(state)) => {
                        let pin = match ExpanderPinMapping::from_u8(pin) {
                            Some(n) => n,
                            None => {
                                error!("Impossible causing pin reached");
                                continue;
                            }
                        };
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

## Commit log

2026-05-19 Added esp32-wroom-c6-1-n8, 20 sk6812mini leds
    [leds.kicad_sch, mcu_extras.kicad_sch, waypoint.kicad_pcb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]
2026-05-20 Added screen with footprint, started to add gps and imu
    [waypoint.kicad_sch]
2026-05-23 Added GNSS, vibration with LRA and Power: Charging, LDO for GNSS, buck for main 3v3 and boost for led 5v
    [power.kicad_sch, waypoint.kicad_sch]
2026-05-27 Finished schematic
    [leds.kicad_sch, mcu_extras.kicad_sch, power.kicad_sch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]
2026-05-29 Placed components (except passives) on pcb
2026-05-30 Placed all passives
    [power.kicad_sch]
2026-05-31 Finished routing and added silkscreen art
    [mcu_extras.kicad_sch, waypoint.kicad_sch]
2026-06-07 Started with firmware, missing display, navigation and leds
    [power.kicad_sch, waypoint.kicad_sch]
2026-06-08 Reorganized, added leds and display setup
2026-06-13 Added zine, readme and small adjustments to pcb
2026-06-14 Added pictures of case, printables, source CAD files, bom and updated README
    [bom.csv, bottom.3mf, buttons.3mf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]
2026-06-17 Added init and deinit calls to logic task and removed dev board specific task
2026-06-17 Removed temporary files / unused files
    [waypoint.csv]
